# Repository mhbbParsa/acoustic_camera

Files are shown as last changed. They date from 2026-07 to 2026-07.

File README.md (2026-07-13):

# Acoustic Camera

https://github.com/user-attachments/assets/35040632-333c-4387-a5bf-bf2f547ff368

A real-time acoustic camera built around a 30-element MEMS microphone array and an FPGA beamformer. The FPGA extracts a single target frequency from every microphone, steers a 32×32 grid of look directions with a CORDIC-based phase rotator, and streams the resulting sound-power map out over UART to a Python viewer with either a plain live heatmap, or overlaid on a webcam feed. A physical switch flips the beamformer between a wide 180° field of view and a zoomed-in 60° view, another five switches set display gain (read back on the board's own 7-segment display), and holding spacebar in the camera overlay re-centers the heatmap on whatever's currently loudest.

Curiosity about phased array radar antennas and electronic beam steering led me to make this more accessible alternative, that replaces the difficult, expensive RF design with acoustic equivalents that are cheap to prototype and safe to probe by hand. The underlying math is identical. Only the wavelength and the hardware changed.

| | |
|---|---|
| Target frequency | 20 kHz (single-bin Goertzel) |
| Array | 30 mics, Fermat/Vogel spiral, ~90 mm diameter (measured from PCB layout) |
| Sample rates | 2 MHz PDM → 62.5 kHz decimated audio (2 MHz / 32) |
| Field of view | 60° (zoomed) or 180° (wide), switch-selectable |
| Angular resolution | ≈11° (rough λ/D estimate at 20 kHz, not a precise figure) |
| Frame rate to host | ≈60 fps (Goertzel-gated, comfortably clears the 2 Mbaud UART link) |
| FPGA | Xilinx Artix-7 `xc7a35tcpg236-1` (Digilent Basys3) |

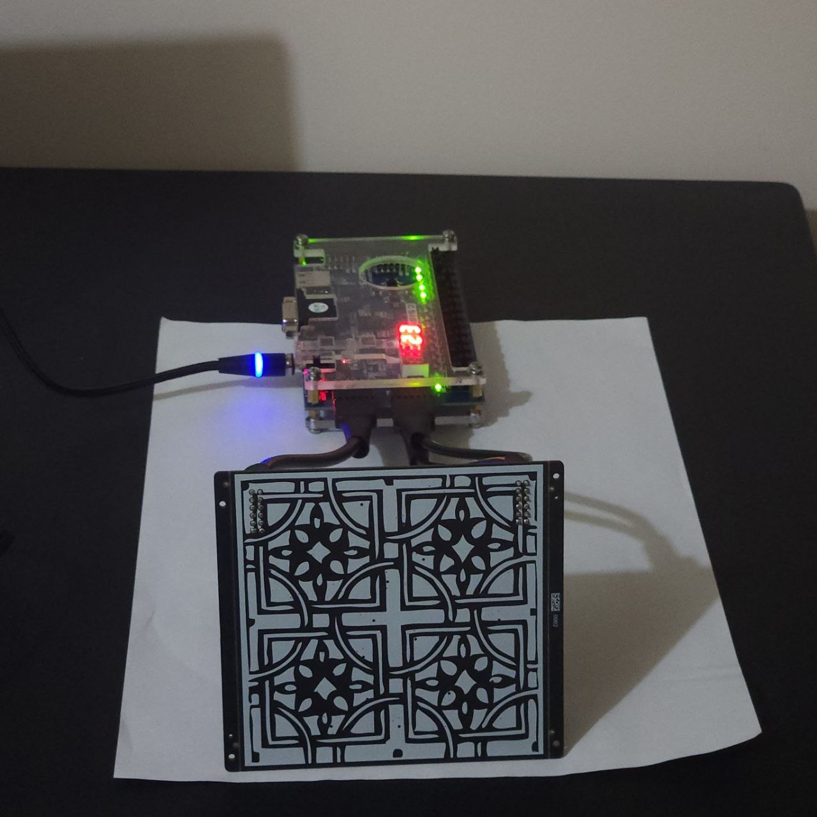
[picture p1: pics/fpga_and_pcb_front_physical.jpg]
FPGA and PCB, physical setup

*20 kHz source → 30-mic PCB → Pmod → Basys3 → USB → host PC live viewer.*

## How it works

```mermaid
flowchart TD
    MIC["30x SPH0641LU4H\nPDM MEMS mics"] -->|"30x 1-bit PDM"| MM["master_mic.sv\nclock gen + time-multiplexed capture"]
    MM -->|"mic_clk"| MIC
    MM -->|"30x PDM"| CIC["CIC.sv\n4th-order CIC decimation"]
    CIC -->|"30x 18-bit PCM"| GZ["goertzel.sv\nsingle-bin DFT @ target freq"]
    GZ -->|"30x (I,Q) phasors"| BF["beamformer.sv\nCORDIC delay-and-sum (cordic_0 IP)"]
    CTRL["zoom + gain switches"] --> BF
    CTRL --> DD["digit_disp.sv + sevenseg.sv\n7-segment gain readout"]
    BF -->|"1024 pixels, 16-bit"| FB["framebuffer.sv\ndouble-buffered BRAM"]
    FB --> UART["UART.sv\n2 Mbaud"]
    UART --> HOST["live_heatmap.py /\ncamera_overlay.py"]
    CAM["webcam"] -->|"camera_overlay.py only"| HOST
```

1. **Acquisition** (`master_mic.sv`) — the 30 microphones are wired as 15 pairs sharing 15 physical pins; even mics are latched on one clock phase, odd mics on the other, so all 30 PDM streams are captured with one `mic_clk`.
2. **Decimation** (`CIC.sv`) — each mic's 1-bit PDM stream is decimated by a 4th-order CIC filter into signed 18-bit PCM audio.
3. **Frequency extraction** (`goertzel.sv`) — a single-bin Goertzel filter (default target: 20 kHz) runs per microphone, producing the real/imaginary component of that mic's signal at the target frequency.
4. **Beamforming** (`beamformer.sv`) — for each of 1024 steering directions (a 32×32 `(u,v)` grid), a Xilinx CORDIC IP core (`cordic_0`) rotates every microphone's phasor by the phase delay for that direction; the rotated phasors are summed and the power is written into the corresponding pixel of a double-buffered block-RAM framebuffer. The **zoom switch** rescales the mic coordinates fed into this calculation, narrowing the steering grid from a 180° field of view down to 60°. The **gain switches** set how far the accumulated power is right-shifted before being stored, controlling display brightness.
5. **Readout** (`UART.sv`) — once a full 1024-pixel frame is ready, it's streamed out at 2 Mbaud (`0xAA 0x55` sync header, then each pixel as 16-bit little-endian) to a host PC.
6. **On-board readout** (`digit_disp.sv` / `sevenseg.sv`) — the current gain value is continuously multiplexed onto the board's two-digit 7-segment display, so gain can be read without a host PC attached.

`vga_controller.sv` is implemented and was tested driving a live monitor earlier in this project; it's currently unused because the framebuffer only exposes a single read port, which is now assigned to UART for host streaming (not an unfinished module).

Mic positions follow a Fermat/Vogel spiral ("sunflower" pattern) so steering delays are computed from fixed-point `(X, Y)` coordinates baked into `beamformer.sv` at synthesis time.

## Design decisions

- **Double buffering, not a single shared framebuffer.** `framebuffer.sv` ping-pongs between two block RAMs: the beamformer always writes into one while UART reads out the other, swapping only once a full frame is ready and UART has finished the previous one. This avoids ever streaming a half-written frame.
- **2 Mbaud specifically.** `CLK_HZ / BAUD = 100,000,000 / 2,000,000 = 50` exactly with an integer UART bit-clock divisor, so there's no baud-rate rounding error accumulating over a frame.
- **Retargeting the Goertzel frequency.** Changing `MIC_HZ` or `DECIMATION_FACTOR` changes the decimated audio sample rate, which shifts which physical frequency the fixed Goertzel coefficients (`COS_w`/`SIN_w`) pick out. This has been verified working down to 10 kHz. That alone does *not* rescale the beamformer's `(X, Y)` mic-position constants, though, which are baked in relative to a reference wavelength; retargeting further out requires regenerating a new coordinate set from `MATLAB/coordinates.m`.

## Live viewer (Python)

Both tools auto-detect the Basys3's UART over USB (FTDI VID:PID `0403:6010`), so no port needs to be specified.

- **`live_heatmap.py`** — a plain live heatmap window. Run it with no arguments.
- **`camera_overlay.py`** — alpha-blends the heatmap over a webcam feed (window 0) instead, with the black→blue→cyan→yellow→red gradient faded in proportionally to signal strength, so quiet regions stay transparent and only real sources light up. A one-pole temporal filter (`PERSISTENCE_DECAY`) smooths frame-to-frame noise. **Hold spacebar** to re-center the heatmap on whatever's currently loudest, correcting for the mic array not being perfectly boresighted with the camera.

```
pip install pyserial opencv-python numpy
python3 live_heatmap.py
python3 camera_overlay.py
```

## Repository layout

| Path | Contents |
|---|---|
| `FPGA/` | Vivado 2025.2 project targeting a Digilent Basys3 (`xc7a35tcpg236-1`). SystemVerilog sources live in `acoustic_camera.srcs/sources_1/new/`, testbenches in `acoustic_camera.srcs/sim_1/new/`. |
| `PCB/` | KiCad project for the 30-mic sensor board (SPH0641LU4H PDM MEMS microphones). |
| `MATLAB/` | Floating-point beamforming simulation and mic-array coordinate generation used to derive the fixed-point constants in `beamformer.sv`. |
| `pics/` | PCB photos/renders and simulated/measured beamformer output, at both FOV settings. |
| `live_heatmap.py`, `camera_overlay.py` | Live viewers for the UART pixel stream (see above). |

## FPGA modules

| Module | Role |
|---|---|
| `acoustic_camera.sv` | Top level; wires the mic front end, Goertzel bank, beamformer, framebuffer, UART, and 7-segment display together. |
| `master_mic.sv` | Mic clock generation and time-multiplexed capture of the 30 PDM lines. |
| `CIC.sv` | 4th-order CIC decimation filter, PDM → 18-bit PCM. |
| `goertzel.sv` | Per-mic single-bin DFT at the configured target frequency. |
| `beamformer.sv` | CORDIC-driven phase-domain delay-and-sum beamformer, 32×32 steering grid, switchable 60°/180° FOV and gain. |
| `framebuffer.sv` | Double-buffered (ping-pong) block-RAM frame store; the beamformer writes one buffer while UART reads out the other. |
| `UART.sv` | Streams a completed frame out at 2 Mbaud once `frame_ready` pulses. |
| `digit_disp.sv` / `sevenseg.sv` | Multiplexes the current gain value onto the board's 7-segment display. |
| `vga_controller.sv` | Reads the framebuffer and drives standard VGA timing; implemented and tested, currently unused (see above). |
| `cordic_0` | Vivado-generated CORDIC IP (phase → sin/cos), used by the beamformer. |

## On-board controls

| Control | Effect |
|---|---|
| `gain[4:0]` (5 switches) | Sets the right-shift applied to each pixel's accumulated power before storage, controls display brightness/sensitivity. Mirrored on the 7-segment display. |
| `zoom` (switch) | 1 = 60° field of view (zoomed in), 0 = 180° field of view (wide). |
| `rst` (button) | Active-low system reset. |

## Pmod wiring

The 30 PDM lines are time-multiplexed down to 15 physical pins (`data[0:14]`, one pair of mics per pin), split across two Basys3 headers. See `FPGA/acoustic_camera.srcs/constrs_1/new/acoustic_camera.xdc` for the exact pin-to-signal mapping and `PCB/` for which physical mic pair lands on each line:

| Header | Signals |
|---|---|
| Pmod JA | `data[8:14]`, `mic_clk` |
| Pmod JXADC | `data[0:7]` |

## Resource utilization

From `FPGA/acoustic_camera.runs/impl_1/` (Vivado 2025.2, `xc7a35tcpg236-1`, fully placed and routed):

| Resource | Used | Available | Utilization |
|---|---|---|---|
| Slice LUTs | 7,439 | 20,800 | 35.8% |
| Slice Registers | 11,511 | 41,600 | 27.7% |
| Block RAM (RAMB18) | 1 | 50 | 2.0% |
| DSP48E1 | 20 | 90 | 22.2% |

Timing closes at 100 MHz (the system clock constraint) with +0.179 ns worst negative slack, and all user-specified constraints met.

## Simulation

- `master_mic_tb.sv`, `beamformer_tb.sv` — unit testbenches for the mic front end and beamformer.
- `acoustic_camera_tb.sv` — drives a synthetic tone into the full pipeline and dumps the resulting frame to `framebuffer.txt`.
- `FPGA/sim_image.py` converts `framebuffer.txt` into a viewable PNG for quick visual inspection of simulation results.

## MATLAB

- `coordinates.m` — generates the Fermat-spiral microphone positions and the fixed-point `(X, Y)` constants consumed by `beamformer.sv`.
- `acoustic_camera.m` — floating-point simulation of the beamforming algorithm, used to validate steering vectors and visualize expected sound-source power maps (at both 60° and 180° FOV) before committing a design to hardware.

## Results

Three stages of validation, from the floating-point reference model down to the physical board:

**1. MATLAB (floating-point algorithm)**

| | 60° FOV | 180° FOV |
|---|---|---|
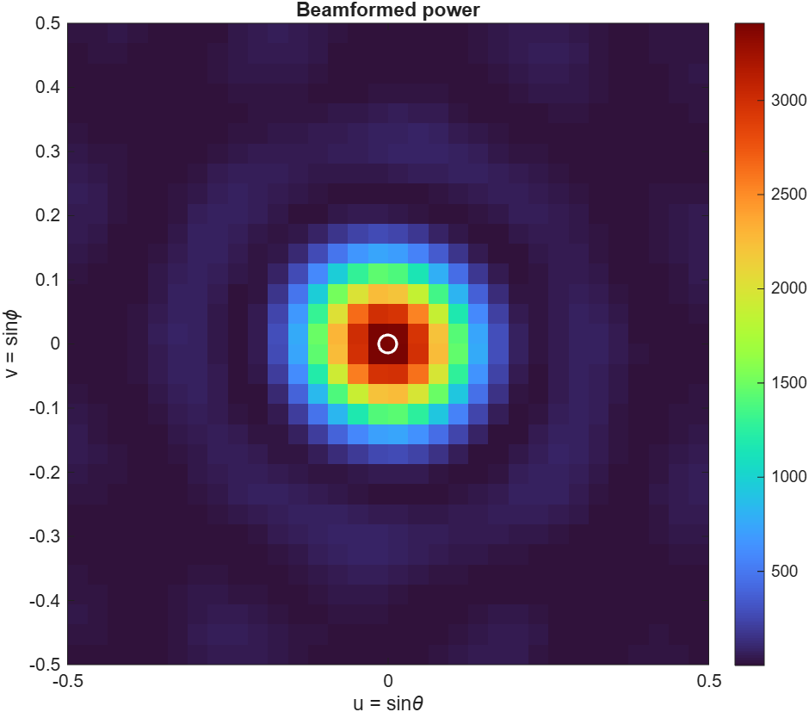
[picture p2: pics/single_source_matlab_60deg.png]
single source, matlab, 60deg
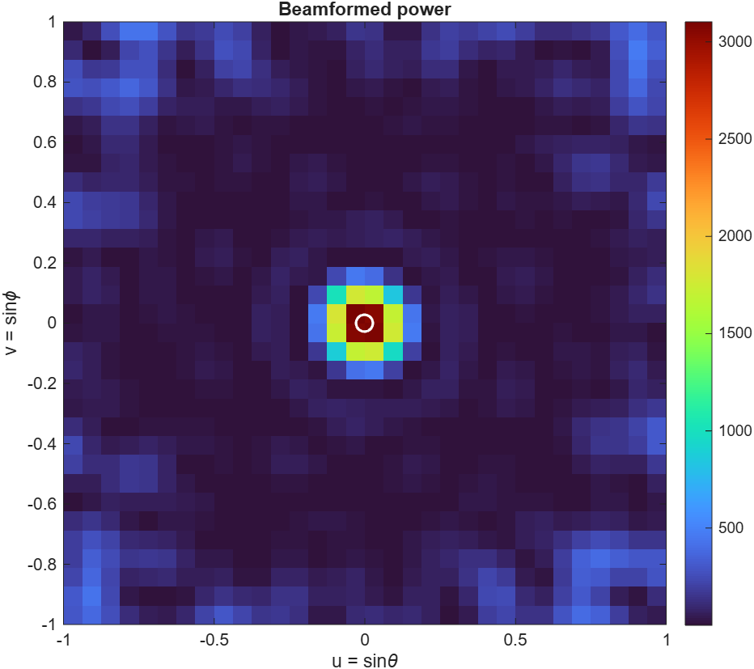
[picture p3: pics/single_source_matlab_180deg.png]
single source, matlab, 180deg
| Single source |  |  |
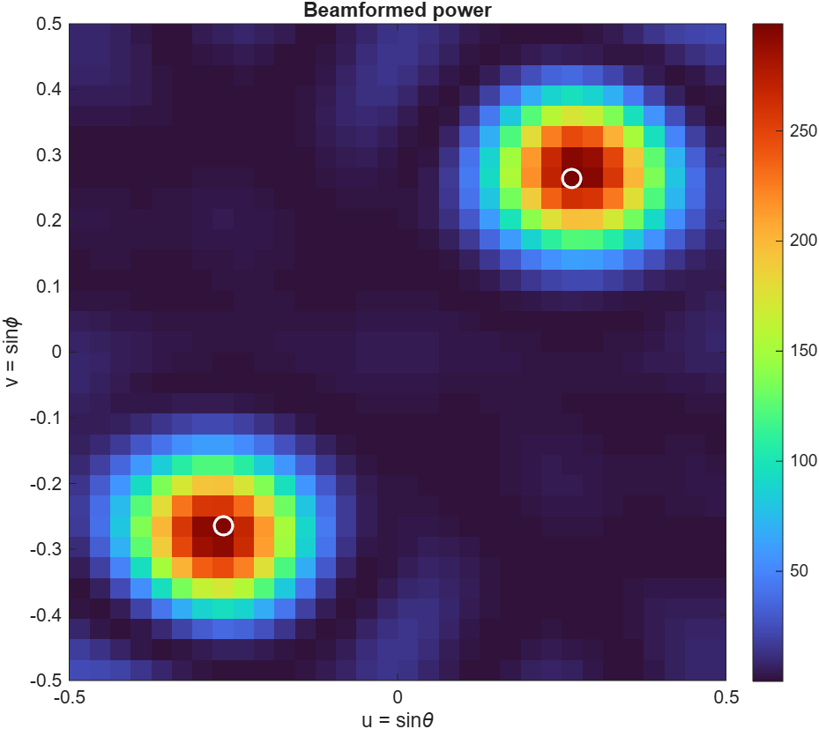
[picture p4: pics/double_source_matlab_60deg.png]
double source, matlab, 60deg
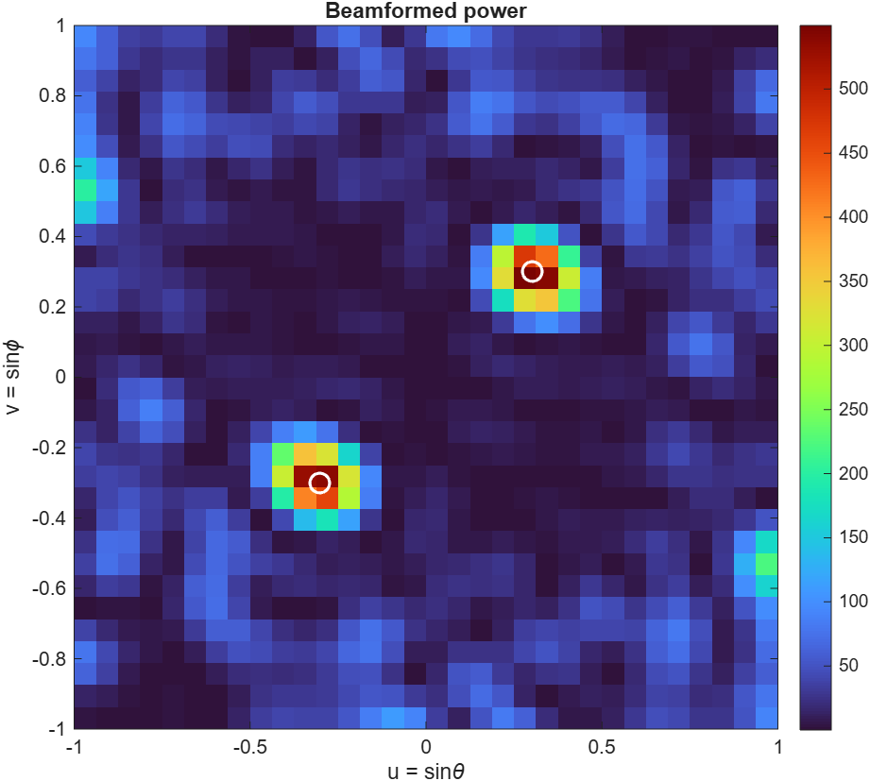
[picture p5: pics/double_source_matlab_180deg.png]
double source, matlab, 180deg
| Double source |  |  |

Double-source scenes are two equal-level 20 kHz sources, ~30° apart. In the 180° views, the region outside the unit circle (u²+v² > 1) is non-physical. Direction cosines beyond that boundary don't correspond to a real look angle, so ignore any energy shown in the corners.

**2. Vivado (RTL simulation)** — confirms the fixed-point SystemVerilog implementation matches the floating-point reference above:

| 60° FOV | 180° FOV |
|---|---|
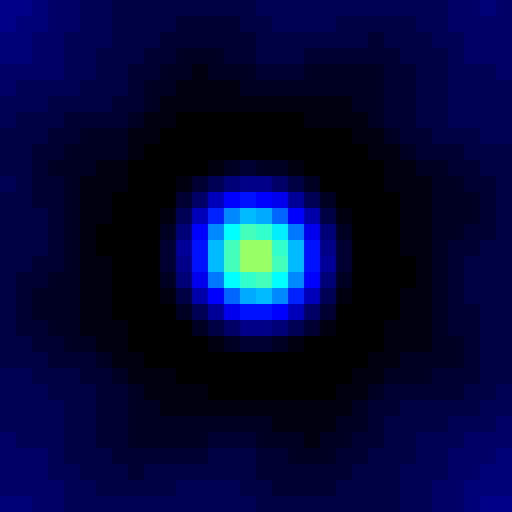
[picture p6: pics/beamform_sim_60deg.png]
Vivado simulation, 60deg
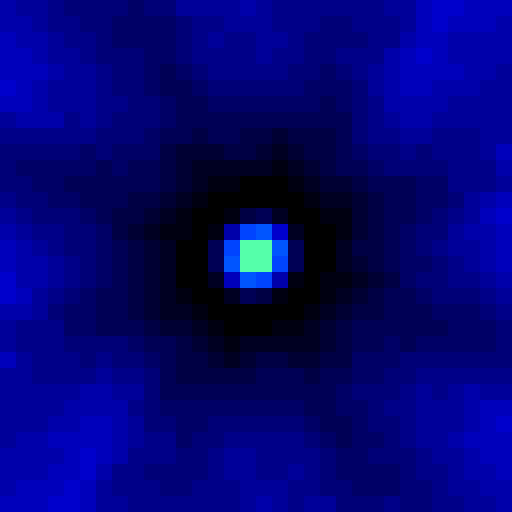
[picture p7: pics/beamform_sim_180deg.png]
Vivado simulation, 180deg
|  |  |

**3. Hardware (live capture)** — via `camera_overlay.py`, at 60° FOV, same two-equal-level-sources-~30°-apart setup as above:

| Single source | Double source |
|---|---|
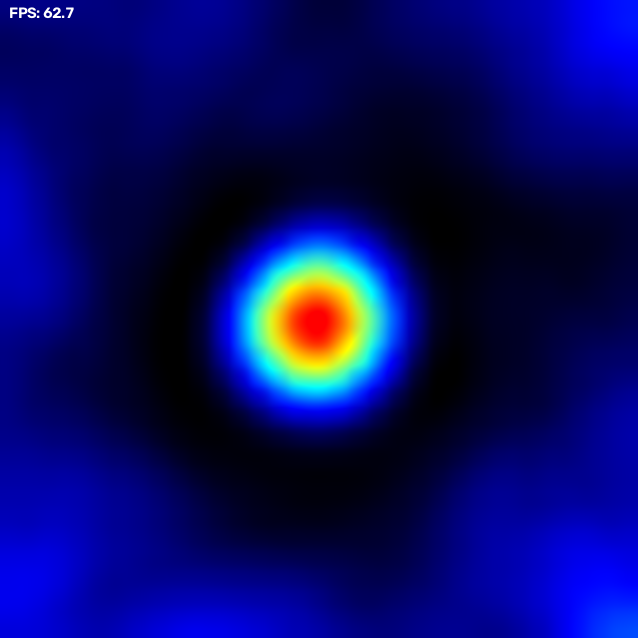
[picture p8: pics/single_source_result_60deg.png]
single source, hardware result
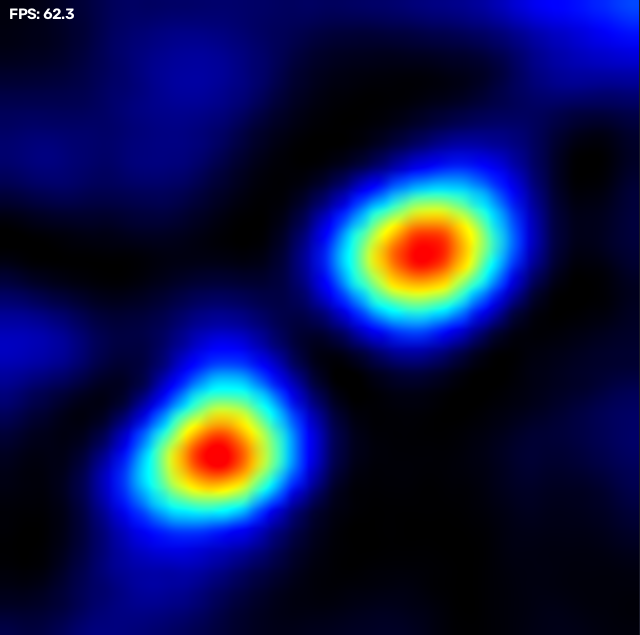
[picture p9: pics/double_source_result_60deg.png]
double source, hardware result
|  |  |

## Hardware

| PCB front (model) | PCB back (model) |
|---|---|
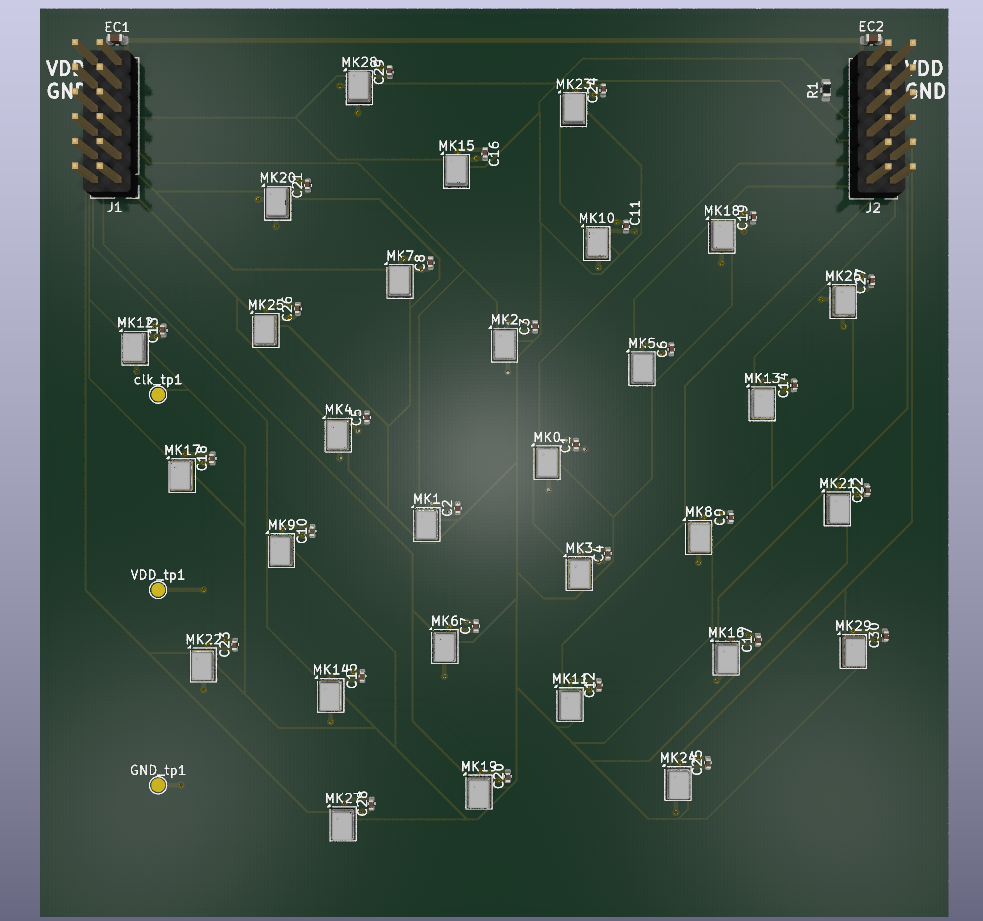
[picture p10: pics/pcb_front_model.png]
PCB front, model
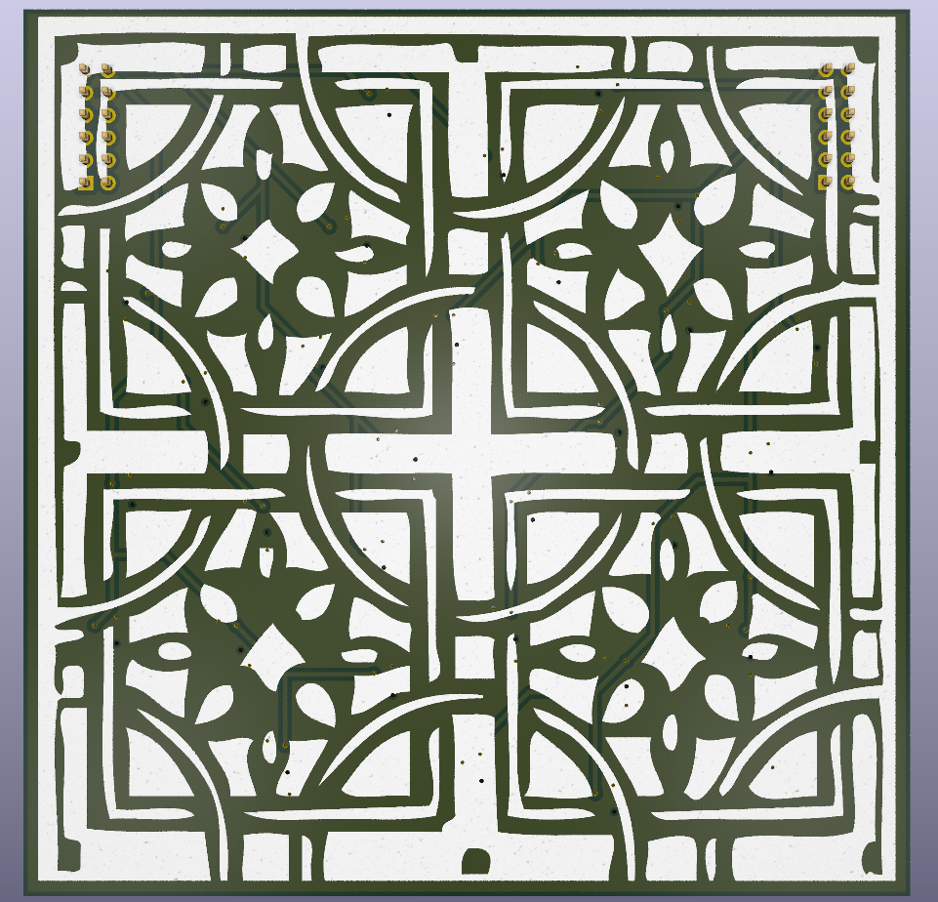
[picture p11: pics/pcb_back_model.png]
PCB back, model
|  |  |

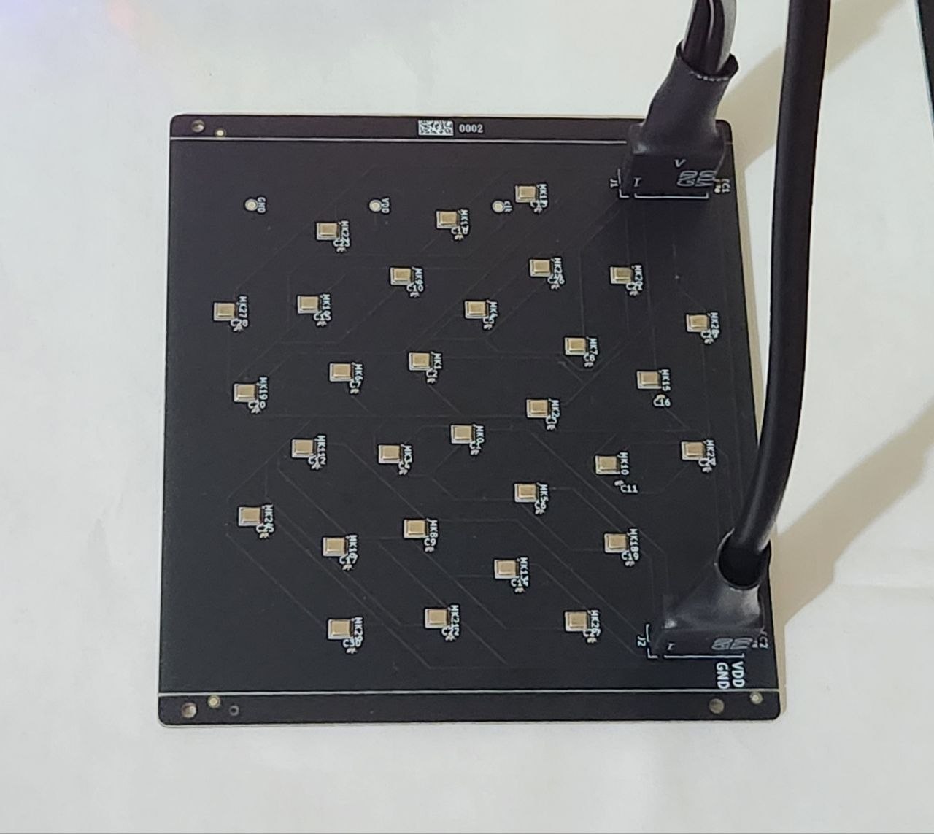
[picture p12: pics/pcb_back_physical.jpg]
PCB back, physical


- 30x Knowles/CUI `SPH0641LU4H` PDM MEMS microphones on a Fermat-spiral array, laid out and placed programmatically via `PCB/script.py` (KiCad scripting console).
- Sensor board connects to the Basys3 over the JA and JXADC Pmod headers (see `FPGA/acoustic_camera.srcs/constrs_1/new/acoustic_camera.xdc`).
- Output is a plain UART TX line, read by a host PC's USB-serial adapter with no VGA monitor needed for normal operation.

## Getting started

- **FPGA**: open `FPGA/acoustic_camera.xpr` in Vivado 2025.2 or later (Basys3 board files required); the CORDIC IP core is regenerated automatically from `cordic_0.xci`.
- **Live viewer**: `pip install pyserial opencv-python numpy`, then run `python3 live_heatmap.py` or `python3 camera_overlay.py` (no arguments needed, both auto-detect the board over USB).
- **PCB**: open `PCB/acoustic_camera.kicad_pro` in KiCad 7+.
- **MATLAB**: run `MATLAB/acoustic_camera.m` for the beamforming simulation, or `MATLAB/coordinates.m` to regenerate the mic array layout constants.

## Status

End-to-end bring-up on hardware works: populated array → FPGA → UART → live heatmap on a host PC, with switchable FOV/gain and an optional webcam overlay. Remaining work is refinement (calibration, image quality) rather than core functionality.

## License

MIT — see [LICENSE](LICENSE).

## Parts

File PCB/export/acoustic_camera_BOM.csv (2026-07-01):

Comment | Designator | Footprint | JLCPCB Part #
100nF | C1 | C_0402_1005Metric | C1525
100nF | C2 | C_0402_1005Metric | C1525
100nF | C3 | C_0402_1005Metric | C1525
100nF | C4 | C_0402_1005Metric | C1525
100nF | C5 | C_0402_1005Metric | C1525
100nF | C6 | C_0402_1005Metric | C1525
100nF | C7 | C_0402_1005Metric | C1525
100nF | C8 | C_0402_1005Metric | C1525
100nF | C9 | C_0402_1005Metric | C1525
100nF | C10 | C_0402_1005Metric | C1525
100nF | C11 | C_0402_1005Metric | C1525
100nF | C12 | C_0402_1005Metric | C1525
100nF | C13 | C_0402_1005Metric | C1525
100nF | C14 | C_0402_1005Metric | C1525
100nF | C15 | C_0402_1005Metric | C1525
100nF | C16 | C_0402_1005Metric | C1525
100nF | C17 | C_0402_1005Metric | C1525
100nF | C18 | C_0402_1005Metric | C1525
100nF | C19 | C_0402_1005Metric | C1525
100nF | C20 | C_0402_1005Metric | C1525
100nF | C21 | C_0402_1005Metric | C1525
100nF | C22 | C_0402_1005Metric | C1525
100nF | C23 | C_0402_1005Metric | C1525
100nF | C24 | C_0402_1005Metric | C1525
100nF | C25 | C_0402_1005Metric | C1525
100nF | C26 | C_0402_1005Metric | C1525
100nF | C27 | C_0402_1005Metric | C1525
100nF | C28 | C_0402_1005Metric | C1525
100nF | C29 | C_0402_1005Metric | C1525
100nF | C30 | C_0402_1005Metric | C1525
1uF | EC1 | C_0603_1608Metric | C15849
1uF | EC2 | C_0603_1608Metric | C15849
SPH0641LU4H-1 | MK0 | Knowles_LGA-5_3.5x2.65mm | C2879853
SPH0641LU4H-1 | MK1 | Knowles_LGA-5_3.5x2.65mm | C2879853
SPH0641LU4H-1 | MK2 | Knowles_LGA-5_3.5x2.65mm | C2879853
SPH0641LU4H-1 | MK3 | Knowles_LGA-5_3.5x2.65mm | C2879853
SPH0641LU4H-1 | MK4 | Knowles_LGA-5_3.5x2.65mm | C2879853
SPH0641LU4H-1 | MK5 | Knowles_LGA-5_3.5x2.65mm | C2879853
SPH0641LU4H-1 | MK6 | Knowles_LGA-5_3.5x2.65mm | C2879853
SPH0641LU4H-1 | MK7 | Knowles_LGA-5_3.5x2.65mm | C2879853
SPH0641LU4H-1 | MK8 | Knowles_LGA-5_3.5x2.65mm | C2879853
SPH0641LU4H-1 | MK9 | Knowles_LGA-5_3.5x2.65mm | C2879853
SPH0641LU4H-1 | MK10 | Knowles_LGA-5_3.5x2.65mm | C2879853
SPH0641LU4H-1 | MK11 | Knowles_LGA-5_3.5x2.65mm | C2879853
SPH0641LU4H-1 | MK12 | Knowles_LGA-5_3.5x2.65mm | C2879853
SPH0641LU4H-1 | MK13 | Knowles_LGA-5_3.5x2.65mm | C2879853
SPH0641LU4H-1 | MK14 | Knowles_LGA-5_3.5x2.65mm | C2879853
SPH0641LU4H-1 | MK15 | Knowles_LGA-5_3.5x2.65mm | C2879853
SPH0641LU4H-1 | MK16 | Knowles_LGA-5_3.5x2.65mm | C2879853
SPH0641LU4H-1 | MK17 | Knowles_LGA-5_3.5x2.65mm | C2879853
SPH0641LU4H-1 | MK18 | Knowles_LGA-5_3.5x2.65mm | C2879853
SPH0641LU4H-1 | MK19 | Knowles_LGA-5_3.5x2.65mm | C2879853
SPH0641LU4H-1 | MK20 | Knowles_LGA-5_3.5x2.65mm | C2879853
SPH0641LU4H-1 | MK21 | Knowles_LGA-5_3.5x2.65mm | C2879853
SPH0641LU4H-1 | MK22 | Knowles_LGA-5_3.5x2.65mm | C2879853
SPH0641LU4H-1 | MK23 | Knowles_LGA-5_3.5x2.65mm | C2879853
SPH0641LU4H-1 | MK24 | Knowles_LGA-5_3.5x2.65mm | C2879853
SPH0641LU4H-1 | MK25 | Knowles_LGA-5_3.5x2.65mm | C2879853
SPH0641LU4H-1 | MK26 | Knowles_LGA-5_3.5x2.65mm | C2879853
SPH0641LU4H-1 | MK27 | Knowles_LGA-5_3.5x2.65mm | C2879853
SPH0641LU4H-1 | MK28 | Knowles_LGA-5_3.5x2.65mm | C2879853
SPH0641LU4H-1 | MK29 | Knowles_LGA-5_3.5x2.65mm | C2879853
33 | R1 | R_0603_1608Metric | C177281

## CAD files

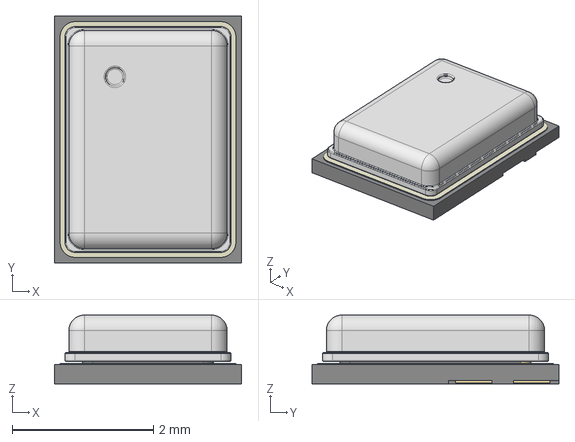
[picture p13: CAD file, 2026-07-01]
PCB/SPH0641LU4H-1.stp
2.65 x 3.50 x 0.976 mm

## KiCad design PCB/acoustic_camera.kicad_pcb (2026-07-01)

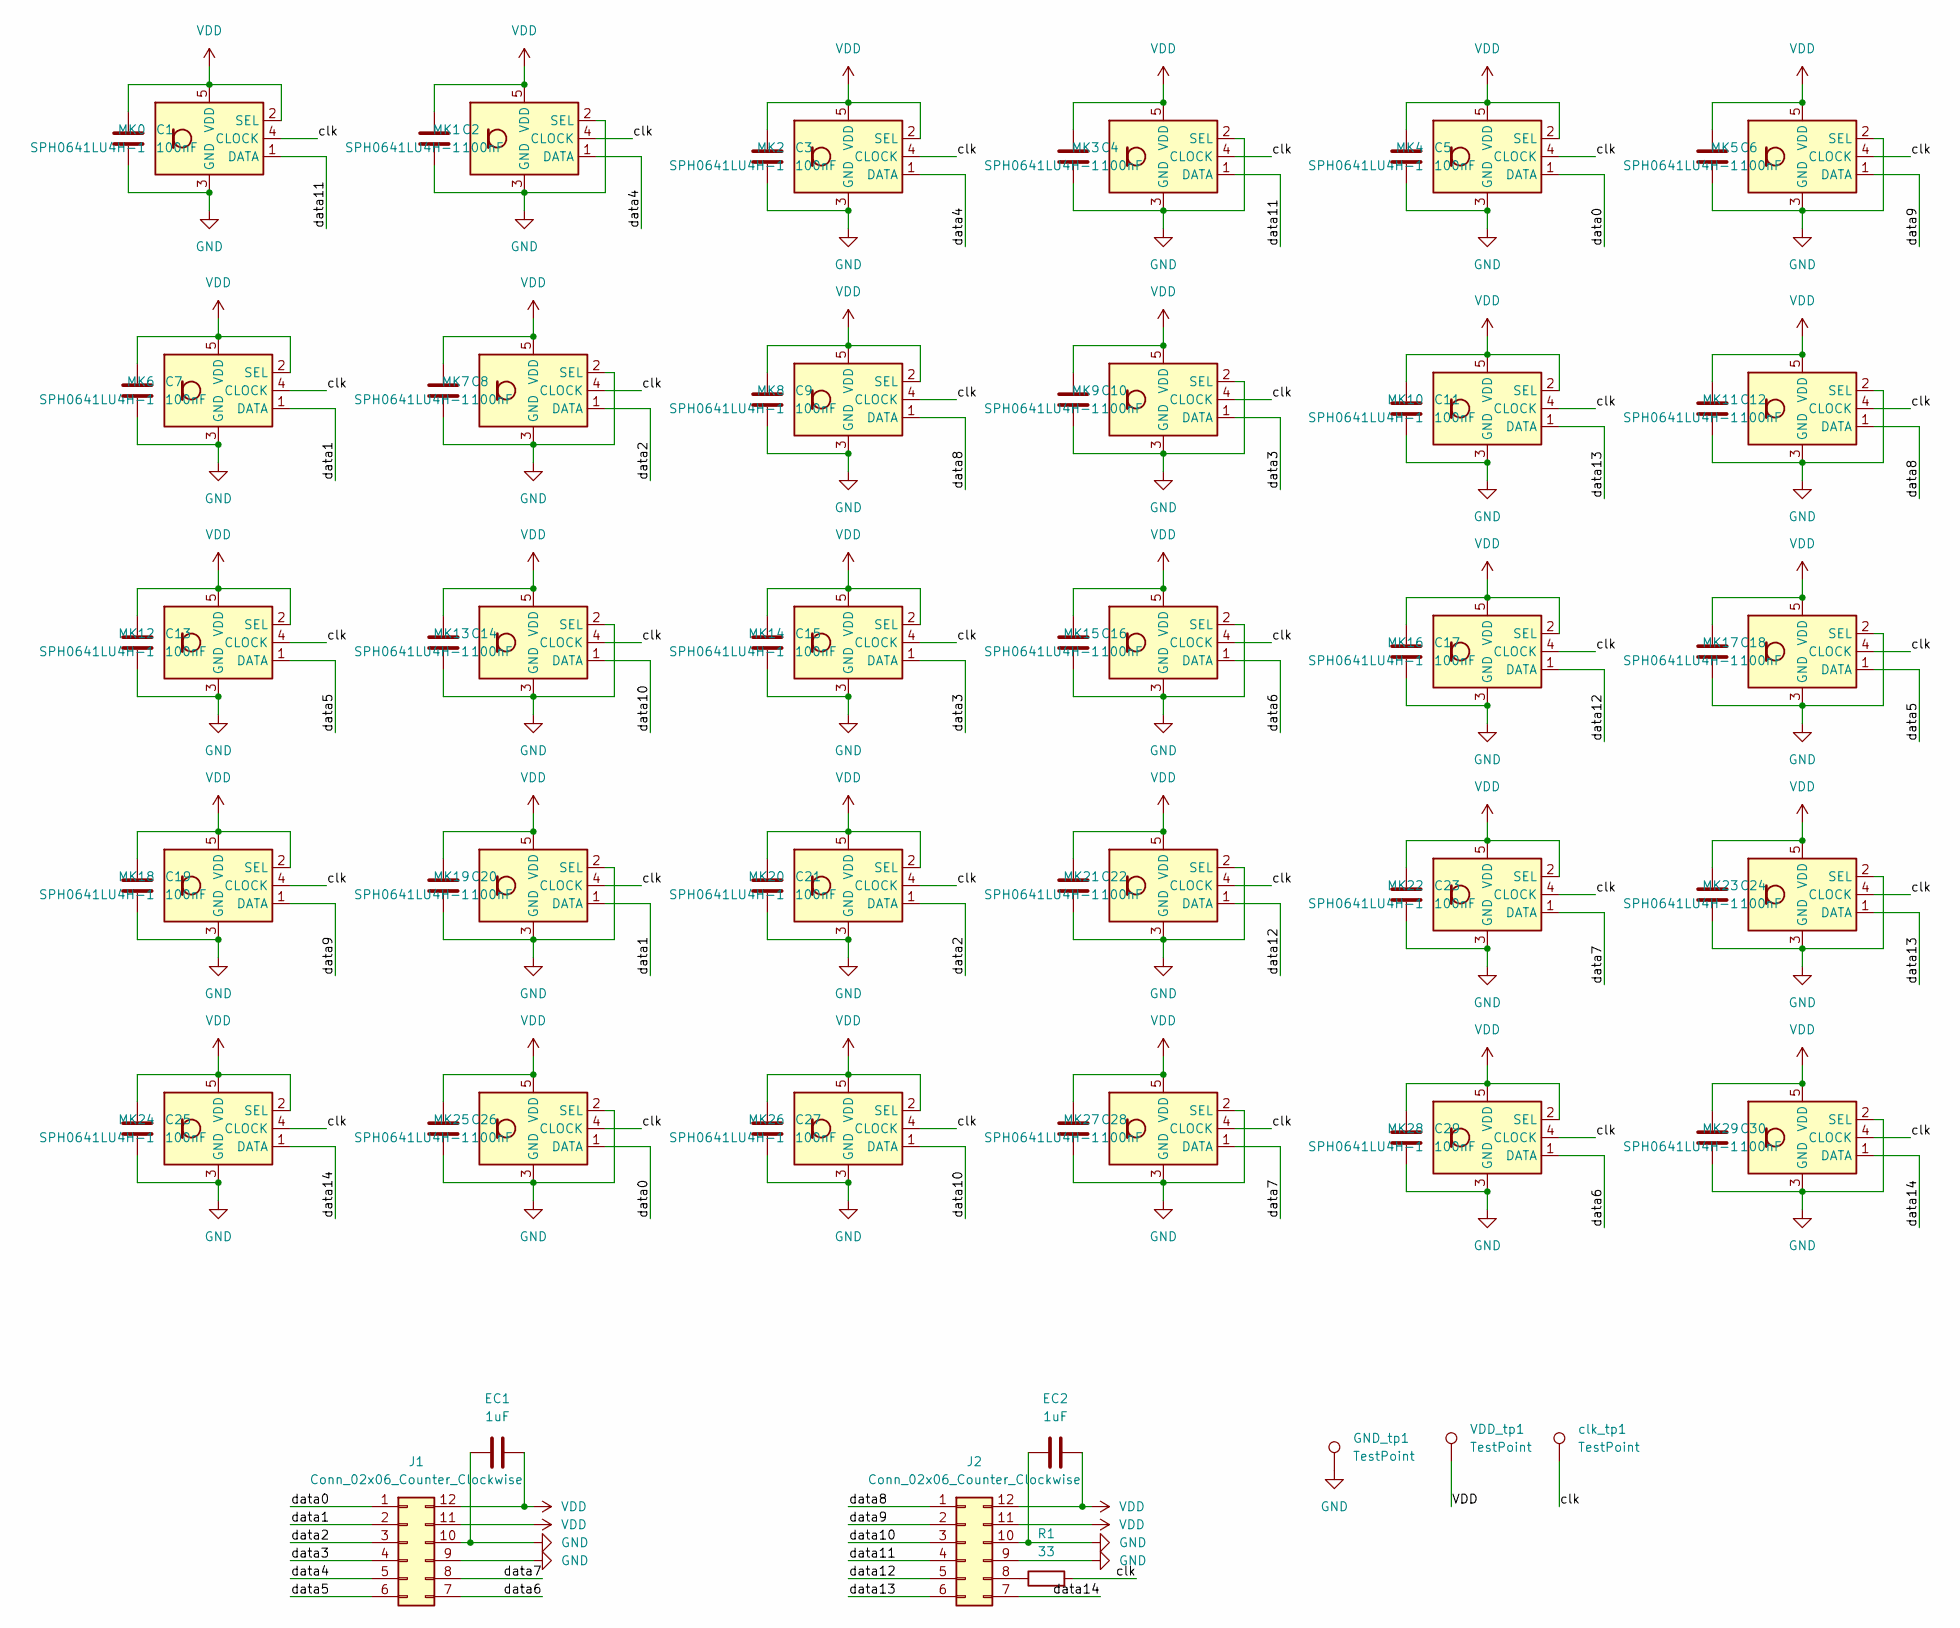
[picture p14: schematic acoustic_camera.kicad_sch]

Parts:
C1, C2, C3, C4, C5, C6, C7, C8, C9, C10, C11, C12, C13, C14, C15, C16, C17, C18, C19, C20, C21, C22, C23, C24, C25, C26, C27, C28, C29, C30: 100nF; C_0402_1005Metric
EC1, EC2: 1uF; C_0603_1608Metric
GND_tp1: TestPoint; TestPoint_Pad_D1.5mm
J1, J2: Conn_02x06_Counter_Clockwise; PinHeader_2x06_P2.54mm_Vertical
MK0, MK1, MK2, MK3, MK4, MK5, MK6, MK7, MK8, MK9, MK10, MK11, MK12, MK13, MK14, MK15, MK16, MK17, MK18, MK19, MK20, MK21, MK22, MK23, MK24, MK25, MK26, MK27, MK28, MK29: SPH0641LU4H-1; Knowles_LGA-5_3.5x2.65mm
R1: 33; R_0603_1608Metric
VDD_tp1: TestPoint; TestPoint_Pad_D1.5mm
clk_tp1: TestPoint; TestPoint_Pad_D1.5mm

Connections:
/clk: MK0.4 (CLOCK), MK1.4 (CLOCK), MK2.4 (CLOCK), MK3.4 (CLOCK), MK4.4 (CLOCK), MK5.4 (CLOCK), MK6.4 (CLOCK), MK7.4 (CLOCK), MK8.4 (CLOCK), MK9.4 (CLOCK), MK10.4 (CLOCK), MK11.4 (CLOCK), MK12.4 (CLOCK), MK13.4 (CLOCK), MK14.4 (CLOCK), MK15.4 (CLOCK), MK16.4 (CLOCK), MK17.4 (CLOCK), MK18.4 (CLOCK), MK19.4 (CLOCK), MK20.4 (CLOCK), MK21.4 (CLOCK), MK22.4 (CLOCK), MK23.4 (CLOCK), MK24.4 (CLOCK), MK25.4 (CLOCK), MK26.4 (CLOCK), MK27.4 (CLOCK), MK28.4 (CLOCK), MK29.4 (CLOCK), R1.2, clk_tp1.1 (1_1)
/data0: J1.1, MK4.1 (DATA), MK25.1 (DATA)
/data1: J1.2, MK6.1 (DATA), MK19.1 (DATA)
/data2: J1.3, MK7.1 (DATA), MK20.1 (DATA)
/data3: J1.4, MK9.1 (DATA), MK14.1 (DATA)
/data4: J1.5, MK1.1 (DATA), MK2.1 (DATA)
/data5: J1.6, MK12.1 (DATA), MK17.1 (DATA)
/data6: J1.7, MK15.1 (DATA), MK28.1 (DATA)
/data7: J1.8, MK22.1 (DATA), MK27.1 (DATA)
/data8: J2.1, MK8.1 (DATA), MK11.1 (DATA)
/data9: J2.2, MK5.1 (DATA), MK18.1 (DATA)
/data10: J2.3, MK13.1 (DATA), MK26.1 (DATA)
/data11: J2.4, MK0.1 (DATA), MK3.1 (DATA)
/data12: J2.5, MK16.1 (DATA), MK21.1 (DATA)
/data13: J2.6, MK10.1 (DATA), MK23.1 (DATA)
/data14: J2.7, MK24.1 (DATA), MK29.1 (DATA)
GND: C1.2, C2.2, C3.2, C4.2, C5.2, C6.2, C7.2, C8.2, C9.2, C10.2, C11.2, C12.2, C13.2, C14.2, C15.2, C16.2, C17.2, C18.2, C19.2, C20.2, C21.2, C22.2, C23.2, C24.2, C25.2, C26.2, C27.2, C28.2, C29.2, C30.2, EC1.1, EC2.1, GND_tp1.1 (1_1), J1.9, J1.10, J2.9, J2.10, MK0.3 (GND), MK1.2 (SEL), MK1.3 (GND), MK2.3 (GND), MK3.2 (SEL), MK3.3 (GND), MK4.3 (GND), MK5.2 (SEL), MK5.3 (GND), MK6.3 (GND), MK7.2 (SEL), MK7.3 (GND), MK8.3 (GND), MK9.2 (SEL), MK9.3 (GND), MK10.3 (GND), MK11.2 (SEL), MK11.3 (GND), MK12.3 (GND), MK13.2 (SEL), MK13.3 (GND), MK14.3 (GND), MK15.2 (SEL), MK15.3 (GND), MK16.3 (GND), MK17.2 (SEL), MK17.3 (GND), MK18.3 (GND), MK19.2 (SEL), MK19.3 (GND), MK20.3 (GND), MK21.2 (SEL), MK21.3 (GND), MK22.3 (GND), MK23.2 (SEL), MK23.3 (GND), MK24.3 (GND), MK25.2 (SEL), MK25.3 (GND), MK26.3 (GND), MK27.2 (SEL), MK27.3 (GND), MK28.3 (GND), MK29.2 (SEL), MK29.3 (GND)
unnamed: J2.8, R1.1
VDD: C1.1, C2.1, C3.1, C4.1, C5.1, C6.1, C7.1, C8.1, C9.1, C10.1, C11.1, C12.1, C13.1, C14.1, C15.1, C16.1, C17.1, C18.1, C19.1, C20.1, C21.1, C22.1, C23.1, C24.1, C25.1, C26.1, C27.1, C28.1, C29.1, C30.1, EC1.2, EC2.2, J1.11, J1.12, J2.11, J2.12, MK0.2 (SEL), MK0.5 (VDD), MK1.5 (VDD), MK2.2 (SEL), MK2.5 (VDD), MK3.5 (VDD), MK4.2 (SEL), MK4.5 (VDD), MK5.5 (VDD), MK6.2 (SEL), MK6.5 (VDD), MK7.5 (VDD), MK8.2 (SEL), MK8.5 (VDD), MK9.5 (VDD), MK10.2 (SEL), MK10.5 (VDD), MK11.5 (VDD), MK12.2 (SEL), MK12.5 (VDD), MK13.5 (VDD), MK14.2 (SEL), MK14.5 (VDD), MK15.5 (VDD), MK16.2 (SEL), MK16.5 (VDD), MK17.5 (VDD), MK18.2 (SEL), MK18.5 (VDD), MK19.5 (VDD), MK20.2 (SEL), MK20.5 (VDD), MK21.5 (VDD), MK22.2 (SEL), MK22.5 (VDD), MK23.5 (VDD), MK24.2 (SEL), MK24.5 (VDD), MK25.5 (VDD), MK26.2 (SEL), MK26.5 (VDD), MK27.5 (VDD), MK28.2 (SEL), MK28.5 (VDD), MK29.5 (VDD), VDD_tp1.1 (1_1)

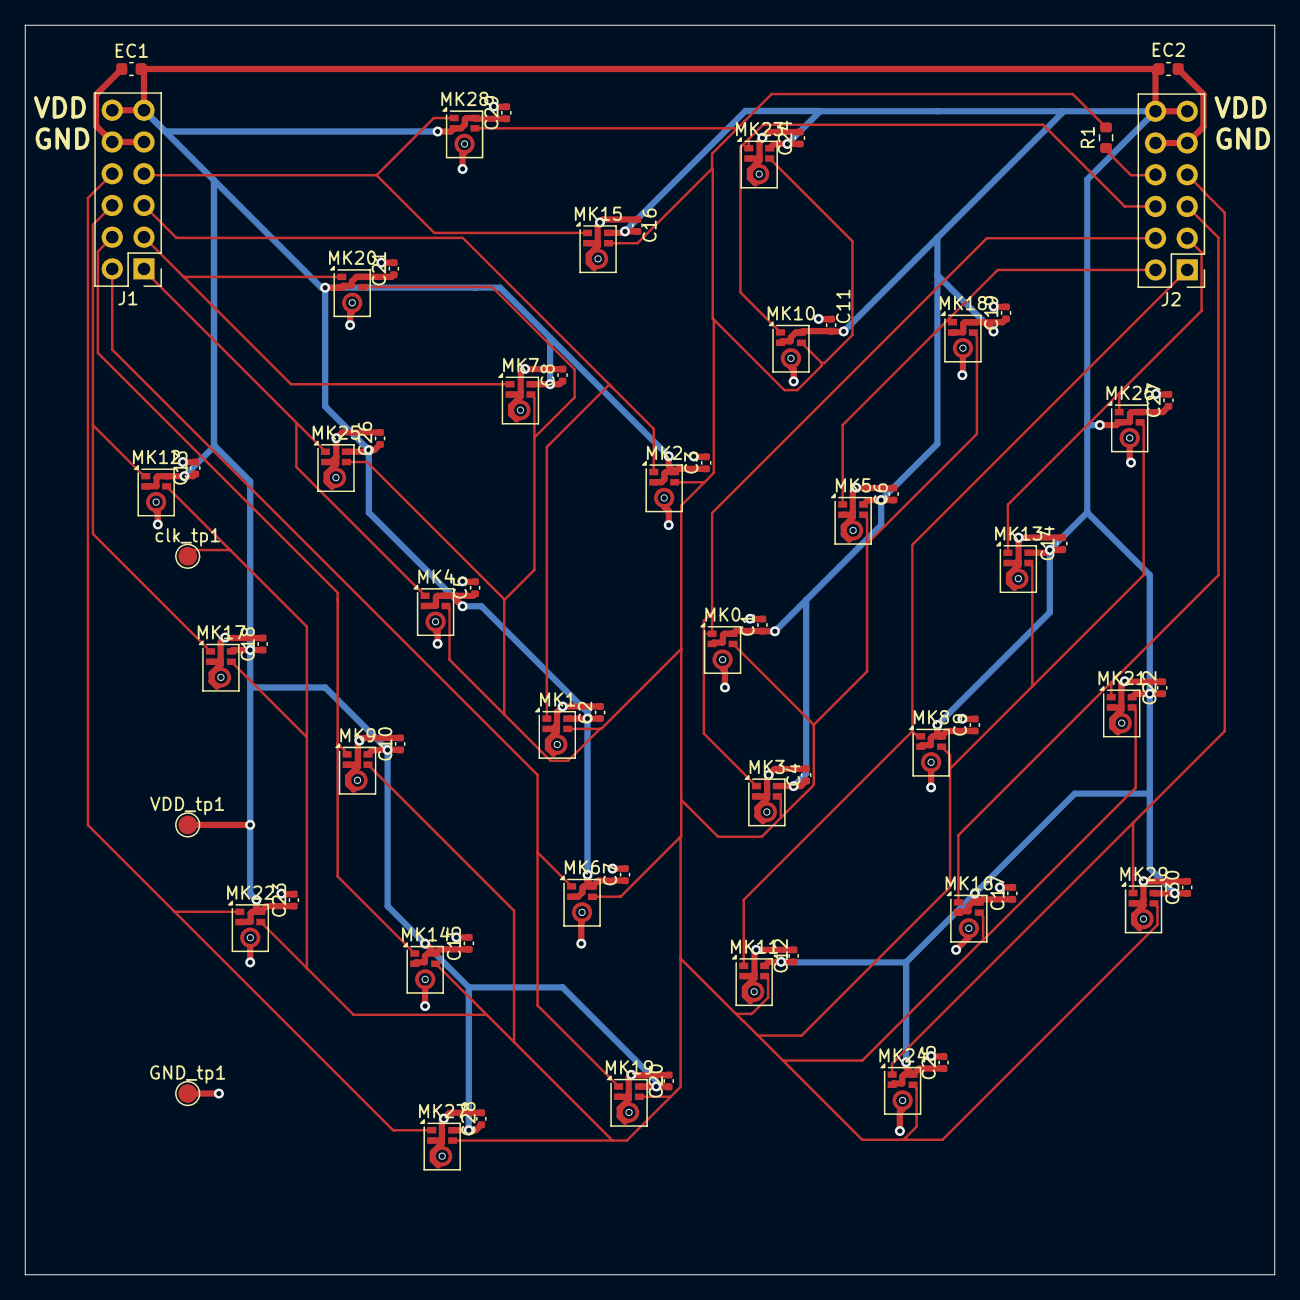
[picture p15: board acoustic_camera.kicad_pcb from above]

Board: 2 copper layers, 100.0 x 100.0 mm, 68 parts (0 on the bottom side), 19 nets.

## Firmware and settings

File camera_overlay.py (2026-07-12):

import queue
import threading
import time
import cv2
import numpy as np
import serial
import serial.tools.list_ports

GRID = 32
FRAME_BYTES = GRID * GRID * 2
DISPLAY_SIZE = 1080
BAUD = 2_000_000
VID = 0x0403
PID = 0x6010
PERSISTENCE_DECAY = 0.60
HEATMAP_MIN_SCALE = 127
FPS_WINDOW = 20


def init_uart(baud=BAUD, vid=VID, pid=PID, timeout=1):
    for p in serial.tools.list_ports.comports():
        if p.vid == vid and p.pid == pid:
            return serial.Serial(p.device, baud, timeout=timeout)
    raise RuntimeError("UART not found")


def uart_thread(ser, out_q, frame_bytes=FRAME_BYTES):
    while True:
        last = ser.read(1)
        current = ser.read(1)
        miss = 0
        while last != b"\xAA" or current != b"\x55":
            last = current
            current = ser.read(1)
            miss = 1
        if miss:
            print("synchronising uart")
        buffer = ser.read(frame_bytes)
        if out_q.empty():
            data_1d = np.frombuffer(buffer, dtype="<u2")
            data_2d = np.reshape(data_1d, (GRID, GRID))
            out_q.put(data_2d)


def data_to_heatmap(data, min_scale=HEATMAP_MIN_SCALE):
    #Black -> blue -> cyan -> yellow -> red

    scale = max(data.max(), min_scale)

    normalized = (data.astype(np.uint32) * 1023 // scale).astype(np.uint16)

    black_to_blue = normalized < 256
    blue_to_cyan = (normalized < 512) & (normalized >= 256)
    cyan_to_yellow = (normalized < 768) & (normalized >= 512)
    yellow_to_red = normalized >= 768

    r = np.zeros_like(normalized, dtype=np.uint8)
    g = np.zeros_like(normalized, dtype=np.uint8)
    b = np.zeros_like(normalized, dtype=np.uint8)

    b[black_to_blue] = normalized[black_to_blue]

    g[blue_to_cyan] = normalized[blue_to_cyan] - 256
    b[blue_to_cyan] = 255

    r[cyan_to_yellow] = normalized[cyan_to_yellow] - 512
    g[cyan_to_yellow] = 255
    b[cyan_to_yellow] = 767 - normalized[cyan_to_yellow]

    r[yellow_to_red] = 255
    g[yellow_to_red] = 1023 - normalized[yellow_to_red]

    rgb = np.stack([b, g, r], axis=-1).astype(np.uint8)
    return rgb, normalized >> 2


def blend_heatmap(frame, heatmap, normalized):
    alpha = normalized

    alpha_resized = cv2.resize(alpha, (frame.shape[1], frame.shape[0]))
    alpha_3ch = np.stack([alpha_resized] * 3, axis=-1)

    blended = (frame.astype(np.uint16) * (255 - alpha_3ch) +
               heatmap.astype(np.uint16) * alpha_3ch) >> 8

    return blended.astype(np.uint8)


def main():
    ser = init_uart()

    q = queue.Queue(maxsize=1)
    t = threading.Thread(target=uart_thread, args=(ser, q), daemon=True)
    t.start()

    cap = cv2.VideoCapture(0)
    ret, frame = cap.read()
    height, width = frame.shape[:2]
    pad = (width - height) // 2

    offset_x, offset_y = 0, 0
    fps = 0
    fps_ctr = 0
    fps_window_start = 0
    key = 0

    persistence = np.zeros((GRID, GRID), dtype=np.float32)
    while True:
        data = q.get()

        if key == ord(" "):
            row, col = np.unravel_index(np.argmax(data), data.shape)
            offset_x = GRID // 2 - col
            offset_y = GRID // 2 - row

        M = np.float32([[1, 0, offset_x], [0, 1, offset_y]])
        data_shifted = cv2.warpAffine(data, M, (GRID, GRID))

        persistence = data_shifted + persistence * PERSISTENCE_DECAY
        heatmap, normalized = data_to_heatmap(persistence)
        heatmap = cv2.resize(heatmap, (DISPLAY_SIZE, DISPLAY_SIZE), interpolation=cv2.INTER_CUBIC)

        ret, frame = cap.read()
        frame = cv2.copyMakeBorder(frame, pad, pad, 0, 0, cv2.BORDER_CONSTANT, value=(0, 0, 0))
        frame = cv2.resize(cv2.flip(frame, 1), (DISPLAY_SIZE, DISPLAY_SIZE), interpolation=cv2.INTER_CUBIC)

        overlay = blend_heatmap(frame, heatmap, normalized)

        fps_ctr += 1
        if fps_ctr == FPS_WINDOW:
            end = time.time()
            fps = FPS_WINDOW / (end - fps_window_start)
            fps_ctr = 0
            fps_window_start = time.time()

        cv2.putText(overlay, f"FPS: {fps:.1f}", (10, 20), cv2.FONT_HERSHEY_SIMPLEX, 0.5, (255, 255, 255), 2)

        cv2.imshow("Heatmap", overlay)

        key = cv2.waitKey(1)
        if key == 27 or cv2.getWindowProperty("Heatmap", cv2.WND_PROP_VISIBLE) < 1:
            break

    cv2.destroyAllWindows()
    ser.close()


if __name__ == "__main__":
    main()

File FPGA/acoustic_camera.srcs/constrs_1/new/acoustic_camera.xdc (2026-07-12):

## This file is a general .xdc for the Basys3 rev B board
## To use it in a project:
## - uncomment the lines corresponding to used pins
## - rename the used ports (in each line, after get_ports) according to the top level signal names in the project

## Clock signal
set_property -dict { PACKAGE_PIN W5   IOSTANDARD LVCMOS33 } [get_ports clk]
create_clock -add -name sys_clk_pin -period 10.00 -waveform {0 5} [get_ports clk]


## Switches
set_property -dict { PACKAGE_PIN V17   IOSTANDARD LVCMOS33 } [get_ports {gain[0]}]
set_property -dict { PACKAGE_PIN V16   IOSTANDARD LVCMOS33 } [get_ports {gain[1]}]
set_property -dict { PACKAGE_PIN W16   IOSTANDARD LVCMOS33 } [get_ports {gain[2]}]
set_property -dict { PACKAGE_PIN W17   IOSTANDARD LVCMOS33 } [get_ports {gain[3]}]
set_property -dict { PACKAGE_PIN W15   IOSTANDARD LVCMOS33 } [get_ports {gain[4]}]
#set_property -dict { PACKAGE_PIN V15   IOSTANDARD LVCMOS33 } [get_ports {sw[5]}]
#set_property -dict { PACKAGE_PIN W14   IOSTANDARD LVCMOS33 } [get_ports {sw[6]}]
#set_property -dict { PACKAGE_PIN W13   IOSTANDARD LVCMOS33 } [get_ports {sw[7]}]
#set_property -dict { PACKAGE_PIN V2    IOSTANDARD LVCMOS33 } [get_ports {sw[8]}]
#set_property -dict { PACKAGE_PIN T3    IOSTANDARD LVCMOS33 } [get_ports {sw[9]}]
#set_property -dict { PACKAGE_PIN T2    IOSTANDARD LVCMOS33 } [get_ports {sw[10]}]
#set_property -dict { PACKAGE_PIN R3    IOSTANDARD LVCMOS33 } [get_ports {sw[11]}]
#set_property -dict { PACKAGE_PIN W2    IOSTANDARD LVCMOS33 } [get_ports {sw[12]}]
#set_property -dict { PACKAGE_PIN U1    IOSTANDARD LVCMOS33 } [get_ports {sw[13]}]
#set_property -dict { PACKAGE_PIN T1    IOSTANDARD LVCMOS33 } [get_ports {sw[14]}]
set_property -dict { PACKAGE_PIN R2    IOSTANDARD LVCMOS33 } [get_ports {zoom}]


## LEDs
set_property -dict { PACKAGE_PIN U16   IOSTANDARD LVCMOS33 } [get_ports {led[0]}]
set_property -dict { PACKAGE_PIN E19   IOSTANDARD LVCMOS33 } [get_ports {led[1]}]
set_property -dict { PACKAGE_PIN U19   IOSTANDARD LVCMOS33 } [get_ports {led[2]}]
set_property -dict { PACKAGE_PIN V19   IOSTANDARD LVCMOS33 } [get_ports {led[3]}]
set_property -dict { PACKAGE_PIN W18   IOSTANDARD LVCMOS33 } [get_ports {led[4]}]
#set_property -dict { PACKAGE_PIN U15   IOSTANDARD LVCMOS33 } [get_ports {led[5]}]
#set_property -dict { PACKAGE_PIN U14   IOSTANDARD LVCMOS33 } [get_ports {led[6]}]
#set_property -dict { PACKAGE_PIN V14   IOSTANDARD LVCMOS33 } [get_ports {led[7]}]
#set_property -dict { PACKAGE_PIN V13   IOSTANDARD LVCMOS33 } [get_ports {led[8]}]
#set_property -dict { PACKAGE_PIN V3    IOSTANDARD LVCMOS33 } [get_ports {led[9]}]
#set_property -dict { PACKAGE_PIN W3    IOSTANDARD LVCMOS33 } [get_ports {led[10]}]
#set_property -dict { PACKAGE_PIN U3    IOSTANDARD LVCMOS33 } [get_ports {led[11]}]
#set_property -dict { PACKAGE_PIN P3    IOSTANDARD LVCMOS33 } [get_ports {led[12]}]
#set_property -dict { PACKAGE_PIN N3    IOSTANDARD LVCMOS33 } [get_ports {led[13]}]
#set_property -dict { PACKAGE_PIN P1    IOSTANDARD LVCMOS33 } [get_ports {led[14]}]
set_property -dict { PACKAGE_PIN L1    IOSTANDARD LVCMOS33 } [get_ports {led[5]}]


##7 Segment Display
set_property -dict { PACKAGE_PIN W7   IOSTANDARD LVCMOS33 } [get_ports {seg[0]}]
set_property -dict { PACKAGE_PIN W6   IOSTANDARD LVCMOS33 } [get_ports {seg[1]}]
set_property -dict { PACKAGE_PIN U8   IOSTANDARD LVCMOS33 } [get_ports {seg[2]}]
set_property -dict { PACKAGE_PIN V8   IOSTANDARD LVCMOS33 } [get_ports {seg[3]}]
set_property -dict { PACKAGE_PIN U5   IOSTANDARD LVCMOS33 } [get_ports {seg[4]}]
set_property -dict { PACKAGE_PIN V5   IOSTANDARD LVCMOS33 } [get_ports {seg[5]}]
set_property -dict { PACKAGE_PIN U7   IOSTANDARD LVCMOS33 } [get_ports {seg[6]}]

set_property -dict { PACKAGE_PIN V7   IOSTANDARD LVCMOS33 } [get_ports dp]

set_property -dict { PACKAGE_PIN U2   IOSTANDARD LVCMOS33 } [get_ports {an[0]}]
set_property -dict { PACKAGE_PIN U4   IOSTANDARD LVCMOS33 } [get_ports {an[1]}]
set_property -dict { PACKAGE_PIN V4   IOSTANDARD LVCMOS33 } [get_ports {an[2]}]
set_property -dict { PACKAGE_PIN W4   IOSTANDARD LVCMOS33 } [get_ports {an[3]}]


##Buttons
set_property -dict { PACKAGE_PIN U18   IOSTANDARD LVCMOS33 } [get_ports rst]
#set_property -dict { PACKAGE_PIN T18   IOSTANDARD LVCMOS33 } [get_ports btnU]
#set_property -dict { PACKAGE_PIN W19   IOSTANDARD LVCMOS33 } [get_ports btnL]
#set_property -dict { PACKAGE_PIN T17   IOSTANDARD LVCMOS33 } [get_ports btnR]
#set_property -dict { PACKAGE_PIN U17   IOSTANDARD LVCMOS33 } [get_ports btnD]
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

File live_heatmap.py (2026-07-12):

import serial
import serial.tools.list_ports
import queue
import threading
import numpy as np
import cv2
import time

def init_uart(BAUD = 2000000, VID = 0x0403, PID = 0x6010, timeout = 1):
    for p in serial.tools.list_ports.comports():
        if p.vid == VID and p.pid == PID:
            ser = serial.Serial(p.device, BAUD, timeout=timeout)
            return ser
    raise RuntimeError("UART not found")

q = queue.Queue(maxsize=1)
def uart_thread(ser, FRAME_BYTES = 2048):
    while True:
        last = ser.read(1)
        current = ser.read(1)
        miss = 0
        while last != b"\xAA" or current != b"\x55":
            last = current
            current = ser.read(1)
            miss = 1
        if miss:
            print("synchronising uart")
        buffer = ser.read(FRAME_BYTES)
        if q.empty():
            data_1d = np.frombuffer(buffer, dtype="<u2")
            data_2d = np.reshape(data_1d, (32, 32))
            q.put(data_2d)


def heatmap(data, MAX_MIN = 255):
    MAX = max(data.max(), MAX_MIN)

    data = data.astype(np.uint32)
    data = (data * 1023 // MAX).astype(np.uint16)

    black_to_blue = data < 256
    blue_to_cyan = (data < 512) & (data >= 256)
    cyan_to_yellow = (data < 768) & (data >= 512)
    yellow_to_red = data >= 768
    
    r = np.zeros_like(data, dtype=np.uint8)
    g = np.zeros_like(data, dtype=np.uint8)
    b = np.zeros_like(data, dtype=np.uint8)

    #r[black_to_blue] = 0
    #g[black_to_blue] = 0
    b[black_to_blue] = data[black_to_blue]

    #r[blue_to_cyan] = 0
    g[blue_to_cyan] = data[blue_to_cyan] - 256
    b[blue_to_cyan] = 255
    
    r[cyan_to_yellow] = data[cyan_to_yellow] - 512
    g[cyan_to_yellow] = 255
    b[cyan_to_yellow] = 767 - data[cyan_to_yellow]

    r[yellow_to_red] = 255
    g[yellow_to_red] = 1023 - data[yellow_to_red]
    #b[yellow_to_red] = 0

    rgb = np.stack([b, g, r], axis=-1).astype(np.uint8)
    return rgb


ser = init_uart()


t = threading.Thread(target=uart_thread, args=(ser,), daemon=True)
t.start()

fps = 0
start = 0
fps_ctr = 0
while True:
    data = q.get()
    rgb = heatmap(data)
    rgb = cv2.resize(rgb, (640, 640), interpolation=cv2.INTER_CUBIC)


    cv2.putText(
        rgb,
        f"FPS: {fps:.1f}",
        (10, 20),                    # x,y position
        cv2.FONT_HERSHEY_SIMPLEX,
        0.5,                           # font scale
        (255, 255, 255),             # colour (B,G,R)
        2                            # thickness
    )
    cv2.imshow("Heatmap", rgb)


    key = cv2.waitKey(1)
    if key == 27 or cv2.getWindowProperty("Heatmap", cv2.WND_PROP_VISIBLE) < 1:
        break

    fps_ctr = fps_ctr + 1
    if fps_ctr == 20:
        end = time.time()
        fps = 20./(end-start)
        fps_ctr = 0
        start = time.time()


cv2.destroyAllWindows()
ser.close()

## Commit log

2026-07-01 timing, handshake and syntax fix
    [acoustic_camera.xdc]
2026-07-12 UART, zoom, python, readme, pics...
